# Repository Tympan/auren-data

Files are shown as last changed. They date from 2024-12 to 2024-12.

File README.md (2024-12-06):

# Auren Data

## Introduction

This repository collect data associated with the Auren hearing probe. The Auren probe interfaces with the Tympan, enabling a wide variety of hearing tests, such as wideband audiometric immitance (WAI) and distortion product otoacoustic emissions (DPOAEs).

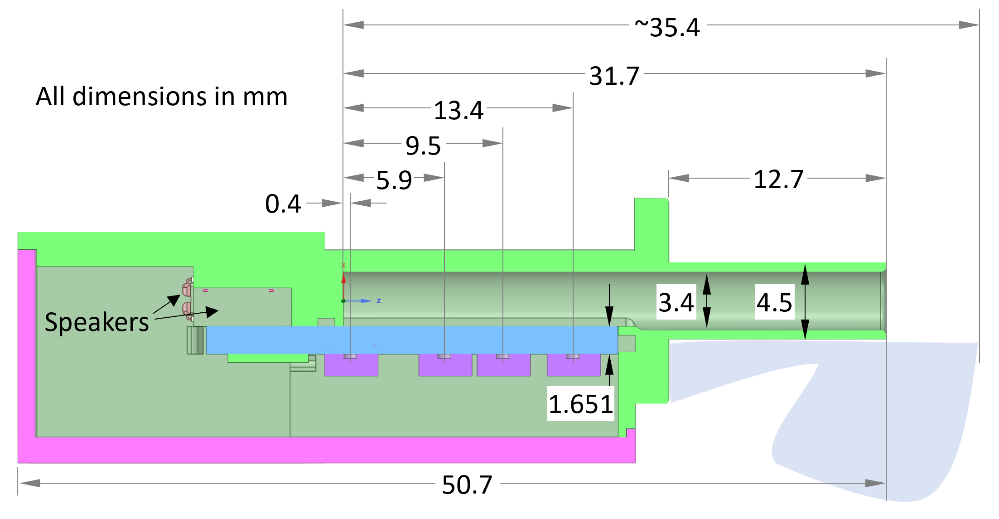
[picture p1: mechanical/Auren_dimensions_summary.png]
Summary of Auren Mechanical Design


This repository contains information about:
* The Auren electrical design
* The Auren mechanical design
* Sample raw calibration data (wav files)
* Sample calibrations (json files)

## Getting Started

To get started with the Auren, start by following the [Getting Started with Tympan Wiki](https://github.com/Tympan/Docs/wiki/Getting-Started-with-Tympan).

The firmware source code for controlling the Auren is located in the [Tympan_Sandbox](https://github.com/Tympan/Tympan_Sandbox/tree/master/OpenHearing/DigMicProbeTest), with a [Precompiled Hex File Here](https://github.com/Tympan/Tympan_Sandbox/tree/master/OpenHearing/_Precompiled). Eventually, this firmware will be moved to this repository.

Once the Auren firmware is running on the Tympan, you can control the hardware through any appropriate serial interface. This includes the Arduino Serial Monitor, or Python!

For an example using the Tympan to calibration the Auren through Python, see the [Auren-Python Calibration Notebook](https://github.com/Tympan/auren-python/blob/main/jupyter_notebooks/Calibration.ipynb).

More details to follow. Feel free to post questions in the Github issues page.

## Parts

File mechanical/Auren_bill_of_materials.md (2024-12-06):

# Bill of Material for Auren Assembly

* Microphones
  * 4x [Infineon-IM72D128](https://www.infineon.com/dgdl/Infineon-IM72D128-DataSheet-v01_01-EN.pdf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)

* Speakers
  * 1x [Knowles RAB-32063-000](https://www.knowles.com/docs/default-source/model-downloads/rab-32063-000.pdf)
  * 1x [Knowles RAU-34832-b148](https://www.knowles.com/docs/default-source/model-downloads/receiver-datasheet-rau-34832-b148.pdf)

* 3D Printed Enclosure
  * `Auren_probe-base.stp` is the file for the base enclosure. This houses the PCB and speakers
  * `Auren_probe-cover.stp` is the file for the cover that encloses the enclosure
  * `Auren_calibration_tubes_micw.stp` is the file for calibration/validation tubes that can be used with a [MicW i436](http://www.micwaudio.com/product.php?id=3) or probe microphone
    * NOTE: The MicW needs an adaptor to work with the Tympan audio input ports

* Other (For PCB)
  * 2x [Mini-USB-B Connector](https://tools.molex.com/pdm_docs/sd/565790519_sd.pdf)
    * Note, we are exploring an alternative connector for the Auren
  * 2x Mini-USB-B male-male cables (custom cables required)

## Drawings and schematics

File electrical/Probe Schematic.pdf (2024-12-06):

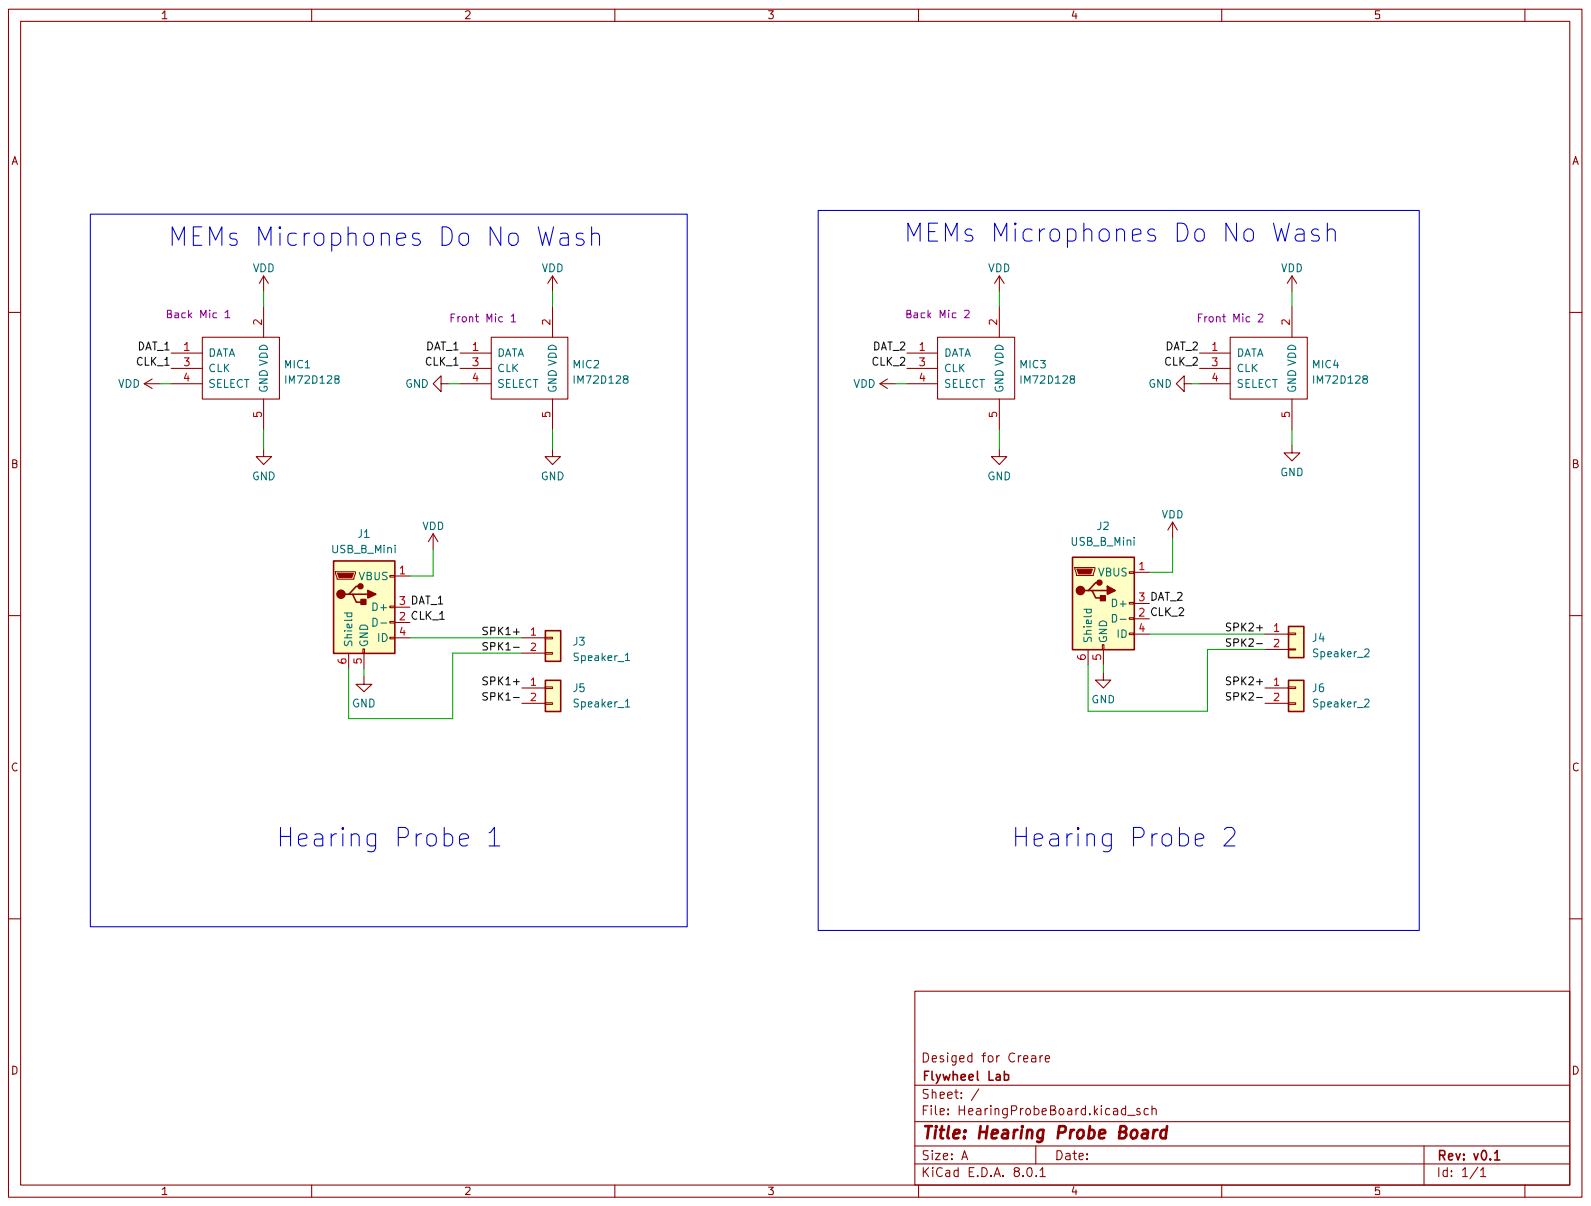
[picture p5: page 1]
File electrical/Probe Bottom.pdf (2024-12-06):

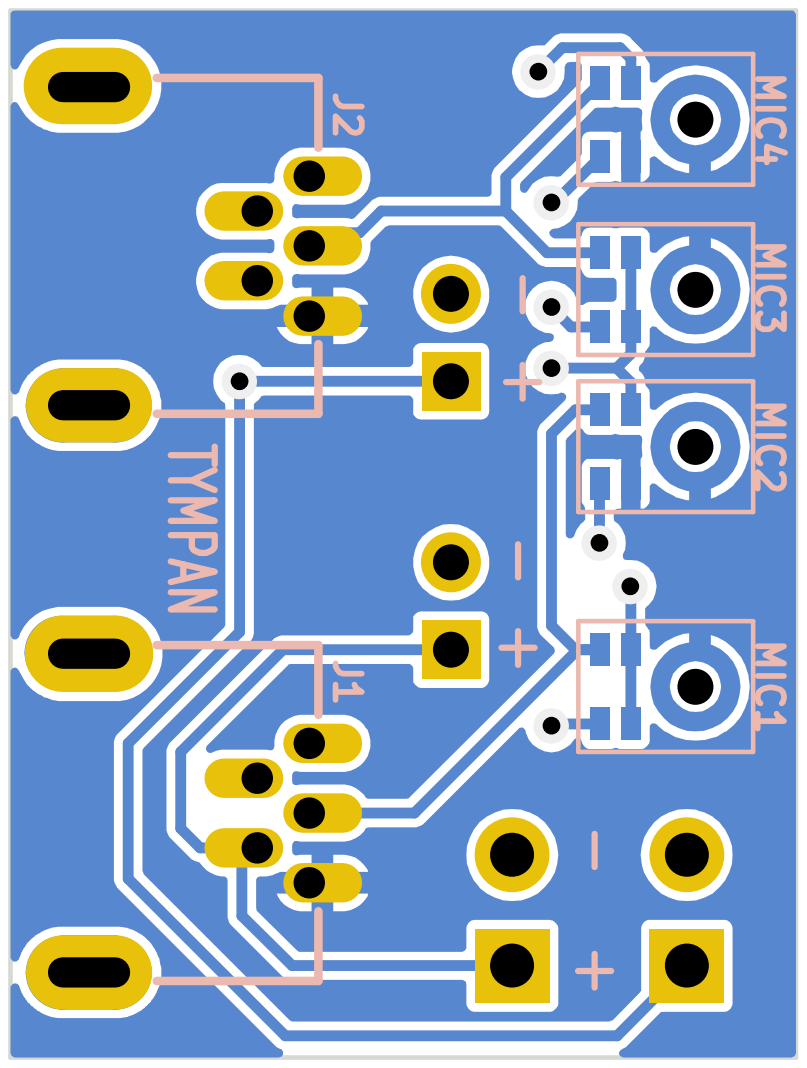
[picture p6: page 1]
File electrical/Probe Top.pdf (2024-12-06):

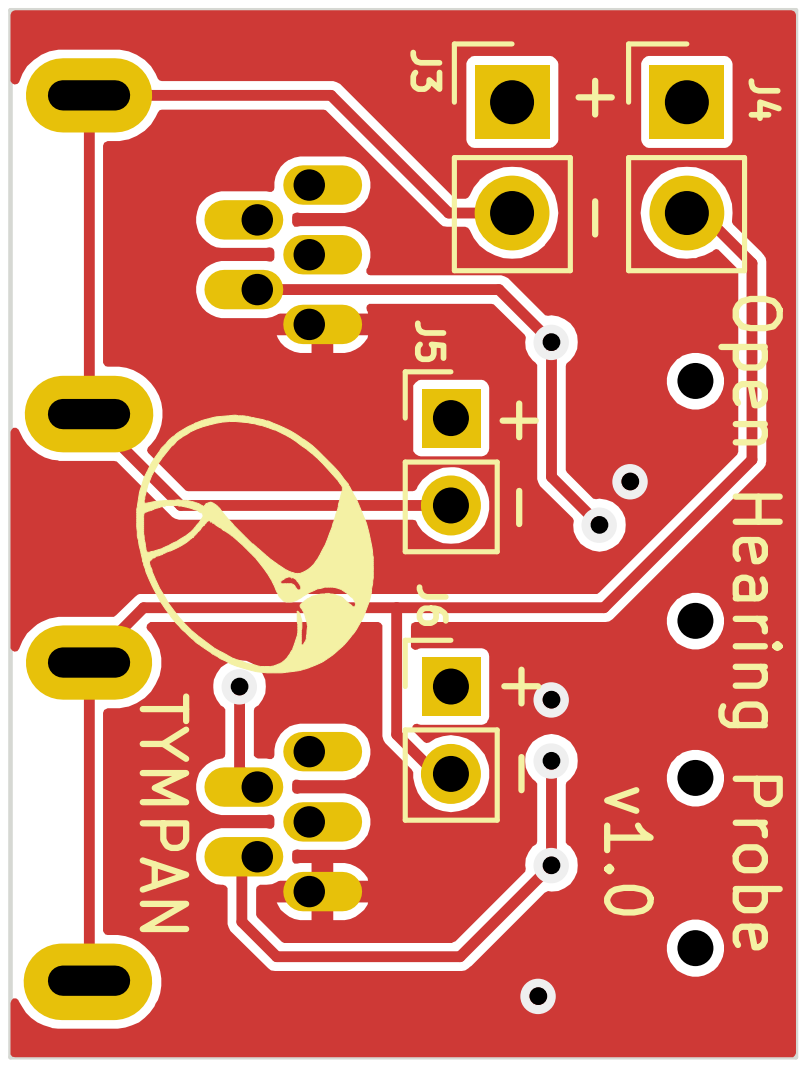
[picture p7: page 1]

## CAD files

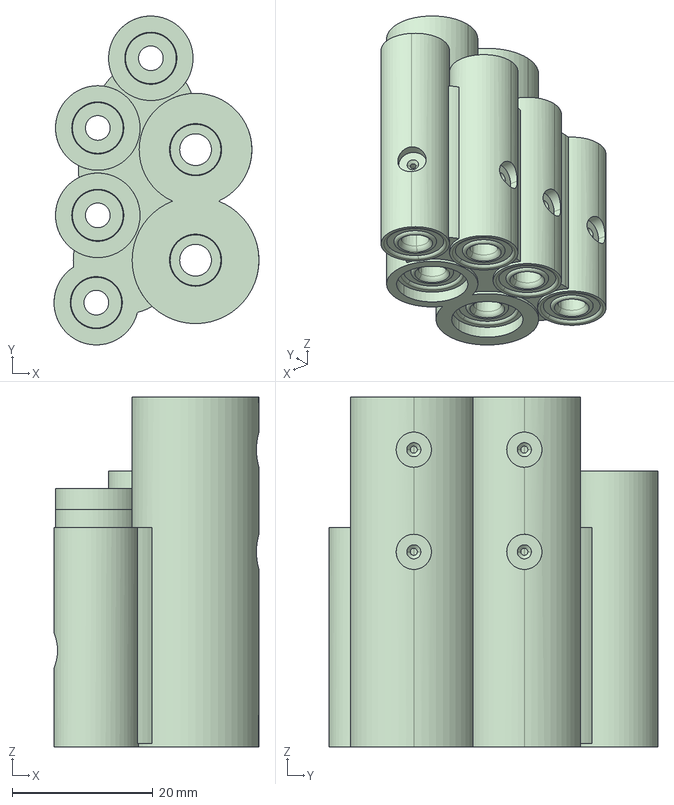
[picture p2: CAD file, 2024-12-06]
mechanical/Auren_calibration_tubes_micw.stp
29.1 x 46.7 x 49.7 mm

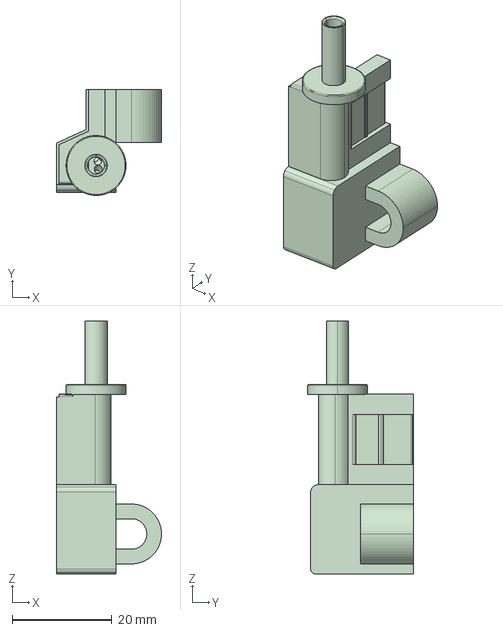
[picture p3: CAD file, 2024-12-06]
mechanical/Auren_probe-base.stp
21.1 x 21.2 x 50.7 mm

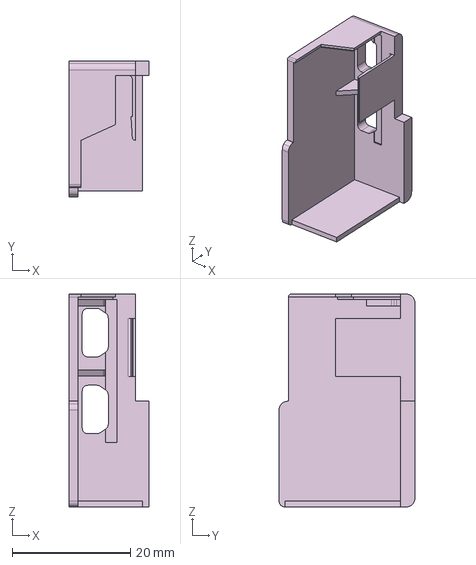
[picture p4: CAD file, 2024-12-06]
mechanical/Auren_probe-cover.stp
13.5 x 23.0 x 36.0 mm
